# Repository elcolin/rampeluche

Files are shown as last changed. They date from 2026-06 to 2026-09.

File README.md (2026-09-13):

# Rampeluche

This project aims to create a two wheel bot capable of SLAM and autonomous navigation.

## Current development

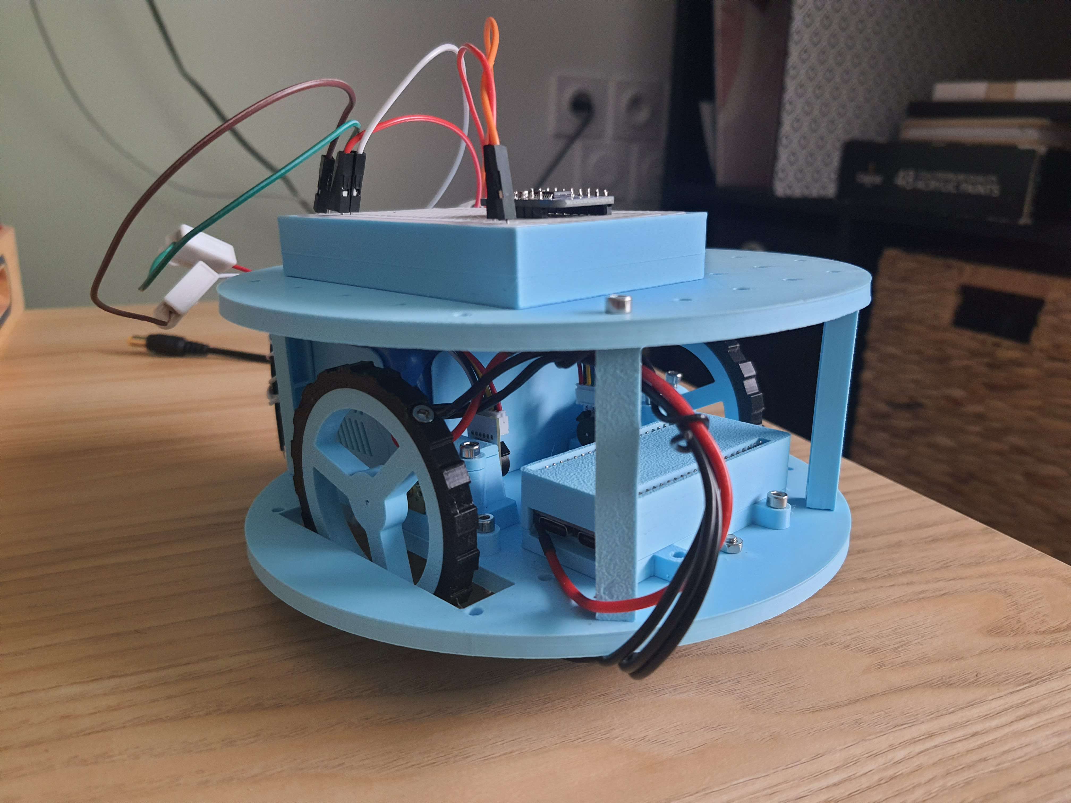
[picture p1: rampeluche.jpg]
Rampeluche


- Keyboard teleoperation (w/a/s/d) over Wi-Fi (SoftAP + raw TCP), with a
  motor safety cutoff if the client disconnects
- Differential drive control through the H-bridge motor driver
- Lidar wired up and its Express Scan frames decoded (checksum-verified,
  angle/distance interpolated), not yet used for obstacle avoidance or SLAM
- Unit tests (Unity, `pio test -e native`) covering the keyboard control
  logic, the Wi-Fi teleop session logic (key decoding, safety timeout),
  RPLidar request-packet encoding, and RPLidar decoding logic

See [rampeluche-esp32/README.md](rampeluche-esp32/README.md) for details.

Issues :  
    - Reduce torque on stall for wheel -> digs into the plastic

## Datasheets

### Motor

Micro motors in the wheels.  
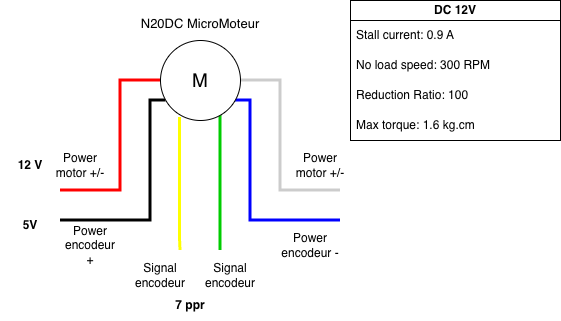
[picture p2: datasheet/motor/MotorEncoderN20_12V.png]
Motor Wheel
    

### Microcontroller

- S3 ESP-32-S3-DevKitC-1 WROOM-1-N16R8
    [Datasheet](datasheet/esp-dev-kits-en-master-esp32s3.pdf)

### Buck convertissor

- VERTER 5V USB Buck-Boost - 500mA from 3V-5V / 1000ma from 5V-12V
    [Datasheet](datasheet/VERTER-5V-USB-Buck-Boost.pdf)

### Motor Driver

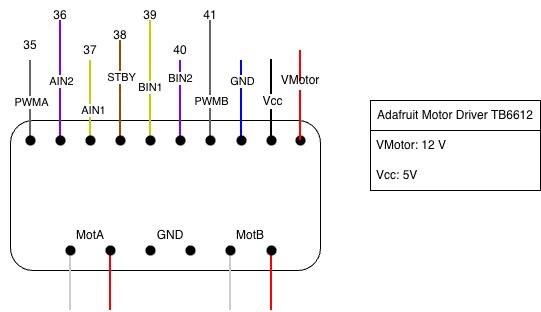
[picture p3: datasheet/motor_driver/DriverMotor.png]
Motor Driver Pinout


- Adafruit TB6612 1.2A DC/Stepper Motor Driver Breakout Board
    [Datasheet](datasheet/motor_driver/adafruit-tb6612-h-bridge-dc-stepper-motor-driver-breakout.pdf)
- TB6612 Chip
    [Datasheet](datasheet/motor_driver/TB6612FNG_datasheet_en_20121101.pdf)

### IMU

- Adafruit LSM9DS1 Accelerometer + Gyro + Magnetometer 9-DOF Breakout
    [Datasheet](datasheet/adafruit-lsm9ds1-accelerometer-plus-gyro-plus-magnetometer-9-dof-breakout.pdf)

### Lidar

- SLAMTEC rplidar A2M8
    [Datasheet](datasheet/LD208_SLAMTEC_rplidar_datasheet_A2M8_v2.6_en.pdf)

## CAD

3d files can be found in the cad file : Lots of models are ORP plateform based.
    [Parts](https://openroboticplatform.com/user:ColorGama)

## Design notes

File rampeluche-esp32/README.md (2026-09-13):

# Rampeluche ESP32

Firmware embarqué du robot Rampeluche : un ESP32-S3 pilote deux moteurs DC
(traction différentielle) et un LIDAR RPLidar, et se laisse téléopérer au
clavier via Wi-Fi (SoftAP + socket TCP brut).

Voir le [README du projet global](../README.md) pour le contexte matériel
(châssis, moteurs, datasheets).

## Vue d'ensemble

```
tools/keyboard_client.py          (PC, Wi-Fi)
        | touche w/a/s/d, toutes les 150 ms, via TCP:1234
        v
   ESP32 SoftAP "ESP32_Control"
        |
   src/main.cpp  (boucle principale)
        |-- lit un octet sur le socket client -> WifiTeleopServer::onKeyReceived()
        |     `-- delegue a KeyboardControl::decodeKey() -> DriveCommand (gauche/droite)
        |-- pas d'octet dispo -> WifiTeleopServer::checkTimeout() (delegue a keyTimedOut())
        |-- applyDriveCommand()/applyMotorCommand() -> DriverMotor -> Motor -> pins PWM/IN1/IN2
        |
        `-- LidCtl.poll(onLidarPoints) -> Serial2 -> RplidarDecoder::StreamDecoder -> Serial (debug)
```

Le robot n'exécute aucune logique de navigation autonome à ce stade : c'est
une téléopération manuelle. Le LIDAR est câblé et initialisé, ses trames sont
décodées par `lib/RplidarDecoder`, mais uniquement pour être affichées sur le
port série (pas encore exploitées pour éviter les obstacles ou faire du
SLAM).

## Structure du code

```
include/            Headers partagés (déclarations de classes, pins)
  pins.hpp            Table de correspondance broches ESP32 <-> matériel
  DriverMotor.h       Regroupe les 2 moteurs (gauche/droite)
  Motor.hpp           Pilotage d'un moteur DC via pont en H
  LidarController.hpp Pilotage du RPLidar sur Serial2 (setup, scan express,
                       poll()) ; delegue l'encodage des requetes a
                       lib/RplidarProtocol et le decodage des trames a
                       lib/RplidarDecoder

src/                 Implémentation, dépend d'Arduino.h / matériel réel
  main.cpp            setup()/loop() : Wi-Fi, serveur TCP (lecture bas niveau du
                       socket uniquement), boucle de pilotage, poll() du LIDAR
                       (LidarController -> RplidarDecoder)
  DriverMotor.cpp
  Motor.cpp
  LidarController.cpp

lib/KeyboardControl/  Logique pure de décision "touche -> commande moteur"
  KeyboardControl.hpp   Types (MotorAction, MotorCommand, DriveCommand),
                         constantes de vitesse/timeout, decodeKey(), keyTimedOut()
  KeyboardControl.cpp   Implémentation, aucune dépendance Arduino/matériel

lib/WifiTeleopServer/ Logique pure de session téléop (au-dessus de KeyboardControl)
  WifiTeleopServer.hpp  Classe WifiTeleopServer : onKeyReceived() (touche -> DriveCommand,
                         reset du timeout), checkTimeout() (latch du stop de sécurité)
  WifiTeleopServer.cpp  Implémentation, aucune dépendance Arduino/matériel

lib/RplidarDecoder/   Logique pure de décodage des paquets "Express Scan"
                      du RPLIDAR A2M8 (synchro, checksum, interpolation
                      angle/distance, resynchronisation sur un flux d'octets)
  RplidarDecoder.hpp    Types (ScanPoint), fonctions de décodage d'un paquet
                        (decodeCapsulePair()...), StreamDecoder (etat +
                        buffering incrementaux, callback de points)
  RplidarDecoder.cpp    Implémentation, aucune dépendance Arduino/matériel

lib/RplidarProtocol/  Logique pure d'encodage des paquets de requête envoyés
                      au RPLIDAR (en-tête, commande, payload, checksum XOR)
  RplidarProtocol.hpp   buildRequestPacket(), requestPacketSize()
  RplidarProtocol.cpp   Implémentation, aucune dépendance Arduino/matériel

test/test_keyboard_control/
  test_main.cpp        Tests unitaires (Unity) de decodeKey()/keyTimedOut(),
                        exécutés hors cible (pas besoin d'ESP32)

test/test_wifi_teleop_server/
  test_main.cpp        Tests unitaires (Unity) de WifiTeleopServer (décodage touche,
                        déclenchement/latch du timeout), exécutés hors cible

test/test_rplidar_decoder/
  test_main.cpp        Tests unitaires (Unity) de lib/RplidarDecoder sur des
                        paquets synthétiques (synchro, checksum, interpolation,
                        resynchronisation), hors cible

test/test_rplidar_protocol/
  test_main.cpp        Tests unitaires (Unity) de lib/RplidarProtocol :
                        encodage de requête (avec/sans payload), checksum,
                        dimensionnement de buffer via requestPacketSize()

test/test_rplidar_decoder_capture/
  test_main.cpp        Test complémentaire optionnel : rejoue une capture
                        réelle du flux lidar (test/fixtures/*.bin, non
                        versionnée) ; s'auto-ignore si le fichier est absent

tools/
  keyboard_client.py    Client Python (PC) : capte w/a/s/d au clavier et les
                         envoie en boucle au robot par TCP
  capture_rplidar_serial.py  Enregistre un flux série (relais Serial2 du
                         lidar) dans un fichier binaire, pour test/fixtures/
                         (voir test/fixtures/README.md)
  requirements.txt

platformio.ini        2 environnements : esp32-s3-devkitc-1 (firmware réel)
                       et native (tests unitaires sur machine de dev)
```

## Choix d'architecture

### Séparer la logique pure du code matériel

`lib/KeyboardControl` ne dépend que de `<cstdint>`, pas d'`Arduino.h`. La
fonction `decodeKey()` (touche -> commandes moteur gauche/droite) et
`keyTimedOut()` (calcul du délai de sécurité) sont des fonctions pures,
sans effet de bord matériel. Ça permet de les tester unitairement sur la
machine de dev, sans flasher un ESP32 à chaque changement, via
l'environnement `native` de PlatformIO :

```sh
pio test -e native
```

`lib/WifiTeleopServer` regroupe la logique d'une session téléop au-dessus de
`KeyboardControl` : la classe `WifiTeleopServer` ne dépend elle non plus que
de `KeyboardControl.hpp`, pas d'`Arduino.h`/`WiFiClient`. `onKeyReceived()`
délègue le décodage à `decodeKey()` et réarme le timeout ; `checkTimeout()`
délègue à `keyTimedOut()` et ne remonte l'ordre de stop qu'une seule fois par
période de silence (`TimeoutResult::triggered`). Testable elle aussi sous
`pio test -e native` (voir `test/test_wifi_teleop_server`).

`src/main.cpp` reste le seul endroit qui connecte cette logique au matériel
réel : la boucle `while (client.connected())` lit les octets bruts du socket
TCP et les pousse à `WifiTeleopServer::onKeyReceived()` (ou appelle
`checkTimeout()` quand rien n'est disponible), puis `applyDriveCommand()`/
`applyMotorCommand()` traduisent le `DriveCommand`/`MotorCommand` obtenu en
appels `Motor::setMotorForward/Backward/stopMotor`. `lib/RplidarDecoder` et
`lib/RplidarProtocol` (voir plus bas) suivent le même principe pour le
protocole LIDAR (décodage des trames reçues / encodage des requêtes
envoyées), via `LidarController::poll()`/`startExpressScan()`. Ce sont les
quatre modules du firmware couverts par des tests aujourd'hui
(`KeyboardControl`, `WifiTeleopServer`, `RplidarDecoder`, `RplidarProtocol`) ;
le reste (moteurs, pilotage LIDAR bas niveau, Wi-Fi bas niveau) n'est
vérifiable qu'en conditions réelles, faute d'abstraction matérielle
testable.

### Coupure de sécurité si le client décroche

`WifiTeleopServer` mémorise l'horodatage de la dernière touche reçue. Si
aucune touche n'arrive pendant `KEY_TIMEOUT_MS` (500 ms, défini dans
`KeyboardControl.hpp`), `checkTimeout()` retourne une commande d'arrêt pour
les deux moteurs, que `main.cpp` applique via `applyDriveCommand()`. Ça
protège contre une perte de connexion Wi-Fi ou un client qui plante avec le
robot lancé. Côté client Python, l'envoi est cadencé à 150 ms
(`SEND_INTERVAL`), volontairement bien en dessous du timeout firmware, pour
qu'un simple relâchement de touche coupe les moteurs de façon réactive sans
attendre le timeout de sécurité.

### Wi-Fi SoftAP + TCP brut, pas de protocole applicatif

L'ESP32 monte son propre point d'accès (`ESP32_Control`) et un
`WiFiServer` TCP sur le port 1234. Le protocole est volontairement minimal :
un caractère par commande (`w`/`a`/`s`/`d`, tout le reste = arrêt), pas de
framing ni de librairie réseau tierce. Suffisant pour une téléopération
directe ; pas conçu pour survivre à plusieurs clients simultanés ou à des
pertes de paquets (TCP masque une partie du problème, mais rien ne gère une
reconnexion propre du serveur après déconnexion du client).

### Contrôle moteur : pont en H, vitesse en pourcentage

`Motor` pilote un pont en H classique (2 entrées logiques IN1/IN2 + 1 PWM,
table de vérité documentée en commentaire dans `DriverMotor.h`). L'API
publique (`setMotorForward/Backward(uint8_t per_speed)`) prend un
pourcentage 0-100 plutôt qu'une valeur PWM brute, pour découpler l'appelant
(`KeyboardControl`, qui définit `FORWARD_SPEED`/`BACKWARD_SPEED`/
`TURN_SPEED` en pourcentage) de la résolution PWM réelle du driver.
`DriverMotor` regroupe les deux `Motor` (gauche/droite) et gère la broche
`STBY` commune aux deux ponts.

### LIDAR : protocole RPLidar "express scan"

`LidarController` orchestre le pilotage du RPLidar sur `Serial2` (`setup()`,
`startExpressScan()`, `poll()`), mais délègue le protocole série à deux libs
pures (`<cstdint>` seul, pas d'`Arduino.h`), testables hors cible via
`pio test -e native`, sur le même principe que `lib/KeyboardControl` :

- `lib/RplidarProtocol` construit les paquets de requête envoyés au lidar
  (`buildRequestPacket()` : en-tête `0xA5` + commande + taille payload +
  payload + checksum XOR). `requestPacketSize(payloadLen)` calcule la taille
  exacte de buffer requise (overhead 4 octets + payload) ; `startExpressScan()`
  dimensionne son buffer avec ce helper plutôt qu'un magic number, pour
  éviter un débordement si la taille du payload change.
- `lib/RplidarDecoder` décode les paquets renvoyés par le lidar (voir
  ci-dessous).

Chaque paquet "capsule" (84 octets) porte un angle de départ en virgule fixe
Q6 (degrés x64) et 16 "cabines" de 2 points chacune (distance en Q2, mm x4,
+ offset d'angle en Q3, 1/8 de degré), format propriétaire Slamtec. L'angle
de chaque point n'étant fiable qu'au début du paquet, `decodeCapsulePair()`
interpole linéairement entre les angles de départ de deux paquets
consécutifs avant d'appliquer l'offset Q3 de la cabine. `StreamDecoder`
consomme le flux d'octets brut de l'UART : il se resynchronise seul sur les
demi-octets de synchro (`0xA`/`0x5`) si l'alignement est perdu (bruit, octet
manqué, redémarrage), vérifie le checksum XOR de chaque paquet, et restitue
les points valides via un callback (`ScanPoint{angle_deg, distance_mm}`).

`LidarController::poll(callback)` lit les octets disponibles sur `Serial2`
(non bloquant) et les transmet au `StreamDecoder`. `main.cpp` l'appelle à
chaque tour de `loop()`, y compris en continu pendant qu'un client de
téléop est connecté (`onLidarPoints` fait un simple `Serial.print` de debug)
— sinon le petit buffer RX matériel de l'UART déborde et le décodage
dégénère en resynchronisations/erreurs de checksum. Aucune structure de
données exploitable par le reste du firmware n'est produite pour l'instant
(pas encore de nuage de points en mémoire, pas de consommateur).

Le décodeur est testé sur des paquets synthétiques
(`test/test_rplidar_decoder`) et, en complément optionnel, sur une capture
réelle du flux série (`test/test_rplidar_decoder_capture`,
`tools/capture_rplidar_serial.py`, voir `test/fixtures/README.md`).
L'encodage des requêtes (`lib/RplidarProtocol`) est testé séparément
(`test/test_rplidar_protocol`) sur des vecteurs de référence issus de la
doc protocole RPLIDAR.

## Table des broches (`include/pins.hpp`)

| Broche ESP32 | Fonction |
|---|---|
| 11 | LIDAR : contrôle moteur (PWM) |
| 12 | LIDAR : RX (UART Serial2) |
| 13 | LIDAR : TX (UART Serial2) |
| 39 / 40 / 41 | Moteur droit : IN1 / IN2 / PWM |
| 37 / 36 / 35 | Moteur gauche : IN1 / IN2 / PWM |
| 38 | STBY commun aux deux ponts en H |

## Compiler, flasher, tester

```sh
# Firmware réel (ESP32-S3), depuis rampeluche-esp32/
pio run -e esp32-s3-devkitc-1
pio run -e esp32-s3-devkitc-1 -t upload
pio device monitor -b 115200

# Tests unitaires (lib/KeyboardControl, lib/WifiTeleopServer,
# lib/RplidarDecoder, lib/RplidarProtocol), sur la machine de dev (pas d'ESP32 requis)
pio test -e native
```

Sur macOS, si `pio test -e native` échoue au link avec une erreur du type
`archive member '/' not a mach-o file`, c'est qu'un `ar` GNU (ex: via
Homebrew binutils) passe avant celui d'Apple dans le `PATH`. Contournement :

```sh
PATH="/usr/bin:$PATH" pio test -e native
```

### Piloter le robot

```sh
cd tools
pip install -r requirements.txt
python3 keyboard_client.py            # se connecte à 192.168.4.1:1234 par défaut
```

Touches : `w` avancer, `s` reculer, `a`/`d` pivoter sur place, relâcher
= arrêt, `q`/Échap pour quitter.

## Dette technique connue

- Le décodage LIDAR (`LidarController::poll()` + `lib/RplidarDecoder`) ne
  fait encore que logger les points sur `Serial` (`onLidarPoints` dans
  `main.cpp`) ; il n'y a pas encore de consommateur de ces données (pas
  d'évitement d'obstacle, pas de SLAM).
- Du code d'encodeur odométrique (interruption `encoderISR`, comptage de
  ticks) est présent dans `main.cpp` mais commenté / non branché.
- `LidarController::startExpressScan()` bloque ~500 ms (`delay()`) le temps
  que le moteur du lidar atteigne sa vitesse nominale. Appelé une seule fois
  au démarrage (premier tour de `loop()`), donc sans impact récurrent
  aujourd'hui, mais à traiter avant toute boucle temps réel plus stricte.
- La boucle `while (client.connected())` de `main.cpp` reste bloquante (elle
  ne rend la main qu'à la déconnexion du client) ; l'extraction de
  `WifiTeleopServer` n'a pas touché à ce point.
- `DriverMotor.h` utilise l'extension `.h` alors que le reste des headers
  du projet utilise `.hpp` — incohérence mineure de nommage.

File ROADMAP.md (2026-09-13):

# Roadmap Rampeluche

Document de suivi technique — état vérifié dans le code/git au 2026-09-13
(mis à jour le même jour : conflit PR #3, nettoyage `WifiHandler.hpp`
constaté fait, extraction `WifiTeleopServer`/`Motor` ajoutée aux actions).
Ne remplace pas README.md / CLAUDE.md (Stack et Architecture y restent la
source de vérité) ; ce fichier trace uniquement les jalons et leurs
dépendances.

## État réel vérifié

- `main` est à jour avec `origin/main` (dernier merge : PR #17, `/feature`
  slash command — tooling agents, hors périmètre firmware de ce document).
  Deux branches restent non mergées :
  - `feat/quadrature-encoders` : ajoute `lib/QuadratureDecoder/` + tests
    Unity (TDD respecté), `Encoder`/`EncoderController`. Pas de PR ouverte,
    juste une branche locale/remote. Ne dépend de rien d'autre, aucun
    conflit connu avec `main`.
  - PR #3 `worktree-rplidar-decoder` (**DRAFT**) : ajoute `lib/RplidarDecoder/`
    (décodeur Express Scan pur, sans `Arduino.h`, fidèle au SDK SLAMTEC),
    12 tests Unity, validation sync/checksum, `LidarController::poll()`,
    outil de capture `tools/capture_rplidar_serial.py`. **Mise à jour :**
    `gh pr view 3` renvoie désormais `mergeable: CONFLICTING` avec `main`
    — un rebase est nécessaire avant de sortir du DRAFT, en plus du
    rebranchement dans `src/main.cpp`.
- `src/main.cpp` (sur `main`) contient encore le prototype `parseExpressPacket()`
  ad-hoc (décodage non testé, pas de checksum ni resynchronisation) et une
  boucle téléop bloquante `while (client.connected())`. Le WiFi/TCP
  (`WiFiServer`, `WiFiClient`, parsing des touches) reste géré inline dans
  ce fichier, sans module dédié.
- `include/WifiHandler.hpp` (coquille vide) a été **supprimé** (PR #19,
  mergée) : la dette "header qui ne fait rien" a disparu, mais le problème
  de fond (Wi-Fi/TCP non extrait en module testable) reste entier — voir
  action court terme "extraire `WifiTeleopServer`" ci-dessous.
- `include/Motor.hpp`/`src/Motor.cpp` et `include/DriverMotor.h`/
  `src/DriverMotor.cpp` : logique PWM/direction correcte (table de vérité
  H-bridge documentée en commentaire) mais couplée à `Arduino.h` dès la
  déclaration — aucune logique pure extraite, donc aucun test Unity
  possible sur ce périmètre aujourd'hui.
- Torque moteur (issue #1, "Configure esp32 signal for torque reduction") :
  **fermée**. `Motor::stopMotor()` met `IN1=LOW, IN2=LOW` ce qui correspond
  bien au mode "Stop" (roue libre) du driver, pas au mode "Short brake" — le
  fix attendu a bien été implémenté. Aucune incohérence de code résiduelle
  détectée sur ce point ; à re-vérifier physiquement si le symptôme
  (moteur qui creuse le plastique) réapparaît.
- IMU LSM9DS1 : aucune trace dans `lib/`, `src/`, `include/` — pas encore
  câblée ni codée. La fusion capteurs (Lidar + IMU) ne peut pas démarrer
  avant son intégration.
- Migration RTOS : le core Arduino-ESP32 embarque déjà FreeRTOS (`loop()`
  tourne dans une tâche FreeRTOS), mais le firmware ne l'utilise pas
  explicitement (une seule boucle séquentielle) — voir issue #13 ci-dessous
  pour la conséquence concrète de ce choix.

### Dette identifiée par le `code-reviewer` (déjà en issues GitHub)

- **Issue #13** — `main.cpp` : la boucle `while (client.connected())`
  bloque tout le reste de `loop()` (dont la lecture `Serial2` du Lidar) tant
  qu'un client téléop reste connecté ; un `delay(500)` supplémentaire
  retarde encore la reprise après déconnexion. Concrètement : dès qu'on
  pilote le robot, le flux Lidar est perdu/désynchronisé. C'est la preuve
  par le code que le découplage FreeRTOS (jalon **M2**) n'est pas un
  exercice théorique mais un prérequis pour que téléop et lecture Lidar
  coexistent.
- **Issue #14** — Logique de protocole RPLidar (`parseExpressPacket`,
  `compute_checksum`, `build_request` dans `main.cpp`/`LidarController.cpp`)
  non extraite dans une lib testable, sans tests Unity, sans validation de
  checksum/sync (désync silencieuse possible). **La PR #3 traite déjà ce
  point** (extraction + 12 tests + validation checksum/sync) ; le travail
  restant est de sortir la PR du mode DRAFT, la rebrancher dans `main.cpp`
  et fermer l'issue #14 à la fusion — pas de le refaire dans un jalon
  ultérieur.

## Prochaines étapes court terme

1. **Merger `feat/quadrature-encoders` (ouvrir une PR).** Indépendant du
   reste, déjà TDD-compliant, aucun conflit connu — à sortir en premier,
   avant la PR #3, pour limiter le risque de conflits supplémentaires sur
   `main.cpp`.
2. **Rebaser la PR #3 sur `main` puis la sortir du DRAFT.** `gh pr view 3`
   montre `mergeable: CONFLICTING` — le rebase est un préalable, distinct
   du rebranchement applicatif. Une fois rebasée : remplacer le bloc
   `Serial2.available() >= 84` / `parseExpressPacket()` de `main.cpp` par
   `LidCtl.poll(onLidarPoints)` (patch documenté dans la description de la
   PR). Ferme l'issue #14.
3. **Extraire un module `lib/WifiTeleopServer/`** pour la logique
   actuellement inline dans `main.cpp` (parsing du flux TCP, gestion du
   timeout clavier) — remplace l'ancienne action "nettoyer
   `WifiHandler.hpp`" (déjà faite via PR #19, mais qui n'a fait que
   supprimer la coquille vide sans combler le vide fonctionnel). Prérequis
   structurel avant de pouvoir écrire l'action 4 sans tout mélanger dans
   `main.cpp`.
4. **Corriger la boucle téléop bloquante (issue #13).** Une fois 1-3
   mergés, remplacer `while (client.connected())` par un poll non bloquant
   dans `loop()` (solution minimale, sans RTOS) OU basculer directement sur
   deux tâches FreeRTOS (téléop / capteurs) si le jalon **M2** est engagé en
   parallèle. Nécessaire avant tout travail de fusion Lidar+IMU puisque le
   Lidar est aujourd'hui silencieusement coupé pendant la conduite.
5. **Extraire la logique PWM/direction pure de `Motor`** dans une fonction
   testable (ex. "quel `IN1`/`IN2`/duty cycle pour telle vitesse/direction
   demandée", sur le modèle de `KeyboardControl`) — aujourd'hui ce calcul
   est correct mais entièrement non testé faute d'extraction hors
   `Arduino.h`.
6. **Intégrer l'IMU LSM9DS1** (lecture brute + tests Unity sur le décodage
   des registres, sur le modèle de `lib/RplidarDecoder`). Aucun travail de
   fusion capteurs n'est possible avant cette étape : c'est un prérequis
   dur pour le jalon **M3**.

## Méthodes/approches possibles

### Structure du code (`lib/<Module>` vs découplage message-passing anticipé)

- **Option A — Un `lib/<Module>` par capteur/actionneur, `main.cpp` réduit
  à un orchestrateur mince (recommandé, prolonge le pattern déjà utilisé
  par `KeyboardControl`, `RplidarDecoder`, `QuadratureDecoder`).**
  Avantages : cohérent avec ce qui passe déjà en TDD ; chaque module reste
  testable isolément (`pio test -e native`) ; chaque module devient une
  unité naturellement encapsulable dans une tâche FreeRTOS pour M2.
  Inconvénients : demande de la discipline pour ne pas laisser la logique
  métier refuir dans `main.cpp` (dérive déjà observée avec
  `parseExpressPacket`).
- **Option B — Introduire dès maintenant des files/queues de
  message-passing entre modules, avant même M2.** Avantages : prépare le
  découplage FreeRTOS en une seule fois. Inconvénients : sur-ingénierie
  tant qu'il n'y a qu'une seule tâche (`loop()`) — complexité ajoutée sans
  bénéfice avant qu'il y ait une vraie concurrence à gérer.
- **Recommandation :** Option A maintenant (actions court terme 1-6
  ci-dessus) ; introduire les files/queues (Option B) seulement au moment
  de M2, quand plusieurs tâches FreeRTOS existeront réellement.

### RTOS : FreeRTOS (déjà présent via Arduino-ESP32) vs bare-metal

- **Option A — Tâches FreeRTOS explicites (recommandé).** Le core
  Arduino-ESP32 tourne déjà sur FreeRTOS ; il suffit de créer des tâches
  dédiées (`xTaskCreatePinnedToCore`) pour téléop, lecture Lidar,
  lecture IMU, contrôle moteur, avec des files (`xQueueSend`/`Receive`)
  pour le découplage. Avantages : résout directement l'issue #13 sans
  réécriture du framework, exploite les deux cœurs du S3, API bien
  documentée. Inconvénients : discipline requise sur les priorités/tailles
  de pile, risque de race conditions sur les ressources partagées
  (`Serial2`, moteurs) si mal cloisonné.
- **Option B — Bare-metal / boucle unique optimisée.** Réécrire `loop()`
  en state machine non bloquante (polling avec timeouts courts partout).
  Avantages : pas de nouvelle dépendance, contrôle total du timing.
  Inconvénients : ne s'attaque pas au fond du problème (un seul thread
  d'exécution) — dès qu'on ajoute IMU + SLAM + téléop + moteurs, la
  complexité de la state machine explose et redevient fragile, ce qui va
  à l'encontre de l'objectif explicite de migration RTOS du CLAUDE.md.
- **Recommandation :** Option A. Le coût de migration est faible (le
  runtime est déjà là), elle répond concrètement à l'issue #13, et elle
  seule tient dans la durée face à l'ajout de l'IMU + SLAM.

### Fusion Lidar + IMU

- **Option A — Complementary/Madgwick filter (orientation IMU) +
  recalage Lidar en aval (scan matching léger, type ICP 2D simplifié).**
  Avantages : coût CPU compatible ESP32-S3 (pas de FPU dédiée mais
  cœurs à 240 MHz suffisants pour un filtre léger), latence prévisible,
  bibliothèques existantes (ex. adaptations de Madgwick/Mahony en C).
  Inconvénients : dérive à long terme si pas de correction extérieure,
  scan matching simplifié moins robuste qu'un SLAM complet en environnement
  dynamique.
- **Option B — EKF (Extended Kalman Filter) fusionnant IMU + odométrie
  encodeurs + recalage Lidar, façon robot_localization/ROS mais réimplémenté
  en C léger.** Avantages : fusion statistiquement correcte, exploite les
  encodeurs déjà présents (`feat/quadrature-encoders`), extensible vers du
  SLAM (ex. gmapping-like) plus tard. Inconvénients : plus complexe à
  implémenter/tester en TDD pur C++ embarqué, coût CPU/mémoire plus élevé
  (matrices, inversions), à valider par profiling sur cible avant de
  s'engager.
- **Recommandation :** commencer par l'Option A (complementary filter +
  odométrie encodeurs) comme brique M3, car les encodeurs et le décodeur
  Lidar existent déjà quasiment testés — livrable rapide et vérifiable en
  Unity. Migrer vers l'EKF (Option B) seulement quand un besoin concret de
  précision de localisation apparaît (jalon SLAM, M5+), pas avant.

## Roadmap par jalons

- **M0 — Consolidation de l'existant (prérequis à tout le reste)**
  - Merge `feat/quadrature-encoders`, rebase + sortie de DRAFT + merge PR #3
    (branchement `LidCtl.poll()` dans `main.cpp`, ferme #14).
  - Extraction `lib/WifiTeleopServer/` (remplace l'ancienne action
    "nettoyer `WifiHandler.hpp`", déjà faite via PR #19).
  - Fix issue #13 (poll non bloquant ou premier découplage FreeRTOS minimal).
  - Extraction de la logique PWM/direction pure de `Motor` (testable Unity).
  - Dépendances : aucune — c'est le socle de tout ce qui suit.

- **M1 — Lidar exploité en continu**
  - Consommer réellement les `ScanPoint` produits par `LidCtl.poll()`
    (aujourd'hui juste affichés en `Serial.print` dans l'exemple de la
    PR #3) : structure de données d'un scan complet, exposition vers le
    reste du firmware.
  - Dépend de M0 (décodeur branché + boucle non bloquante, sinon le flux
    reste coupé pendant la téléop).

- **M2 — Découplage FreeRTOS (tâches téléop / Lidar / moteurs)**
  - Implémenter l'option A ci-dessus (tâches + files) si le fix minimal de
    M0 pour #13 n'est qu'un pansement (poll) plutôt qu'une vraie séparation.
  - Dépend de M0 ; conditionne la suite car IMU + fusion + SLAM ajoutent
    des flux concurrents supplémentaires qu'une boucle unique ne pourra
    plus absorber.

- **M3 — Intégration IMU LSM9DS1 + odométrie**
  - Driver I2C/SPI + décodage registres testé en Unity (sur le modèle
    `lib/RplidarDecoder`), fusion basique avec les encodeurs
    (`feat/quadrature-encoders`) pour une estimation de pose odométrique.
  - Dépend de M2 (une tâche IMU dédiée a besoin du découplage RTOS pour ne
    pas être bloquée par la téléop, même problème que le Lidar aujourd'hui).

- **M4 — Fusion Lidar + IMU (complementary filter, Option A)**
  - Recalage des scans Lidar avec l'orientation/déplacement estimés par
    IMU+encodeurs (M3).
  - Dépend de M1 (scans exploitables) et M3 (odométrie disponible).

- **M5 — Cartographie / SLAM léger**
  - Occupancy grid ou scan-matching incrémental, adapté aux ressources
    ESP32-S3 (pas de SLAM complet type Cartographer sur ce MCU — à évaluer :
    exécution locale minimale vs déport du calcul lourd sur un hôte via
    WiFi, à trancher une fois M4 mesuré en pratique).
  - Dépend de M4.

- **M6 — Navigation autonome de base (évitement d'obstacles)**
  - Boucle de contrôle réactive sur la carte/scan fusionné, sans ML.
  - Dépend de M5 (ou au minimum de M4 si une navigation réactive pure
    Lidar+IMU suffit avant d'avoir une carte).

- **M7 — Machine learning**
  - Une fois qu'un pipeline de perception fiable et testé existe
    (M4-M6), envisager un modèle embarqué (classification d'obstacles,
    apprentissage de trajectoire) — prématuré tant que la donnée capteur
    fusionnée n'est pas stable et vérifiée par tests.
  - Dépend de M4 au minimum (données de fusion propres), idéalement M5/M6.

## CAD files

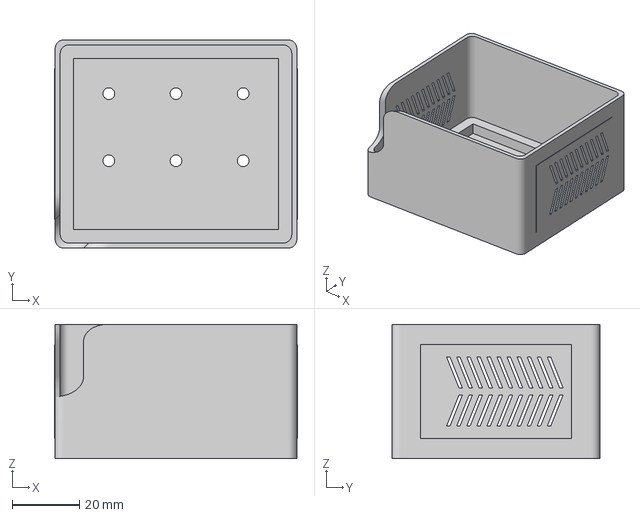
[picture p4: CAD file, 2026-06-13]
cad/battery holder.3mf
72.4 x 62.0 x 40.0 mm

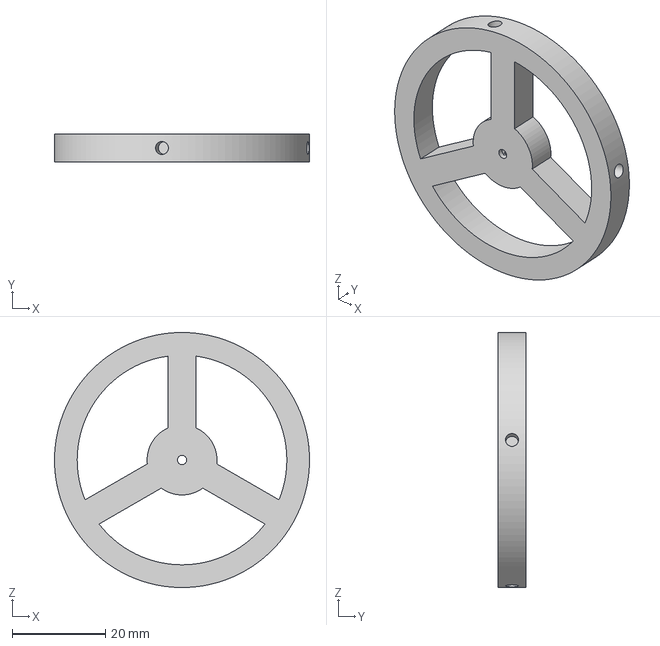
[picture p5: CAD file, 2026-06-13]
cad/roue_n20.3mf
54.7 x 6.00 x 54.7 mm

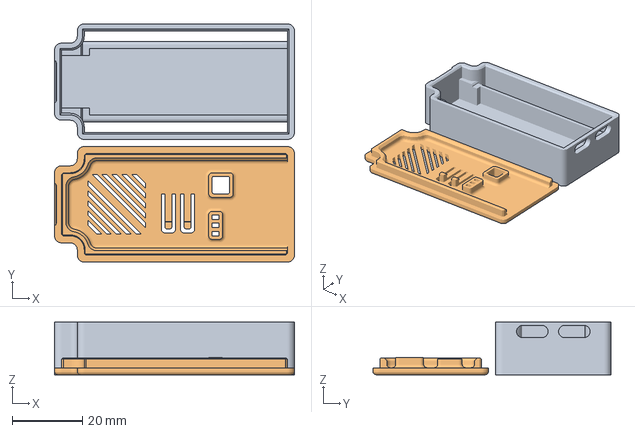
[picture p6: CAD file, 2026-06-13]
cad/ESP32_S3_WROOM_Case.3mf
68.5 x 68.0 x 15.0 mm
ESP32_S3_WROOM_Case.stl_1
ESP32_S3_WROOM_Case.stl_2

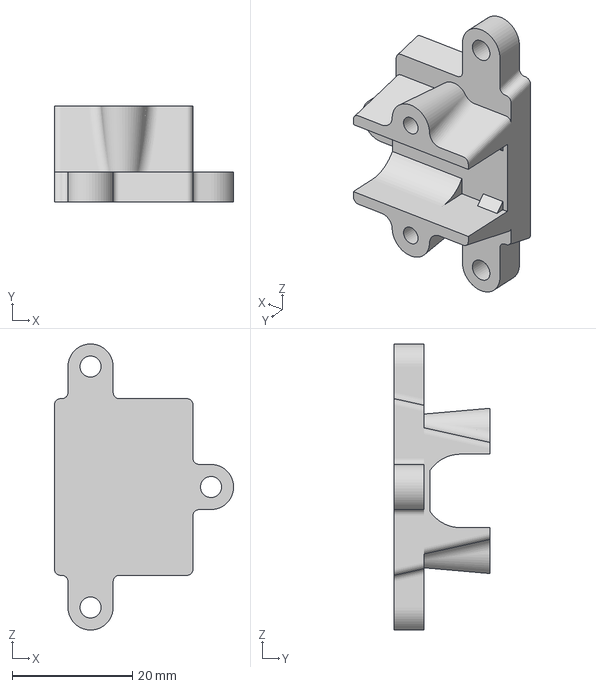
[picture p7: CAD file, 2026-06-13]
cad/motormount.3mf
29.7 x 16.0 x 47.5 mm

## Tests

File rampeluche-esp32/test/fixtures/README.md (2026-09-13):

# Fixtures de test (captures reelles du RPLIDAR A2M8)

`test_rplidar_decoder_capture` verifie le decodeur sur un enregistrement reel
du flux serie du lidar, en complement des paquets synthetiques de
`test_rplidar_decoder`. Ce fichier binaire n'est pas versionne (specifique a
un capteur/une session de capture) : chacun genere le sien localement.

## 1. Generer la capture

### Via l'ESP32 (cablage actuel : lidar relie uniquement a Serial2)

Remplacer temporairement le contenu de `loop()` dans `src/main.cpp` par un
simple relais brut Serial2 -> Serial :

```cpp
void loop() {
    static bool started = false;
    if (!started) {
        delay(500);
        LidCtl.startExpressScan();
        started = true;
    }
    while (Serial2.available()) {
        Serial.write(Serial2.read());
    }
}
```

Flasher (`pio run -t upload`), puis sur la machine de dev (`pip install
pyserial` si besoin) :

```
python3 tools/capture_rplidar_serial.py <port_serie_esp32> 5 test/fixtures/rplidar_a2m8_express_scan.bin
```

`<port_serie_esp32>` : le port USB de l'ESP32 (visible dans
`pio device monitor` ou le moniteur serie, ex. `/dev/tty.usbmodem14201` sur
macOS, `COM5` sur Windows). 5 secondes suffisent largement a couvrir
plusieurs tours, meme a vitesse de rotation reduite.

Remettre ensuite `loop()` dans son etat normal une fois la capture faite :
ce bloc n'est qu'un outil de capture, pas du code a garder en place.

### Via un adaptateur USB-TTL branche directement sur le lidar

Si le RPLIDAR est cable sur un adaptateur USB-TTL independant de l'ESP32, le
meme script peut lire directement le port serie du lidar. Il faut alors,
avant de lancer la capture : alimenter/piloter le moteur (ce projet utilise
une broche PWM dediee, pas de DTR automatique comme sur l'adaptateur
officiel Slamtec) et envoyer la commande Express Scan
(`0xA5 0x82 0x05 0x00 0x00 0x00 0x00 0x00 0x22`) sur ce port.

## 2. Emplacement attendu

```
test/fixtures/rplidar_a2m8_express_scan.bin
```

`test_rplidar_decoder_capture` l'ignore proprement (`IGNORE`, pas `FAIL`)
si le fichier est absent : `pio test -e native` passe sans lui, c'est un
test complementaire pour qui a le materiel sous la main.

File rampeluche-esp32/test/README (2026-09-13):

This directory is intended for PlatformIO Test Runner and project tests.

Unit Testing is a software testing method by which individual units of
source code, sets of one or more MCU program modules together with associated
control data, usage procedures, and operating procedures, are tested to
determine whether they are fit for use. Unit testing finds problems early
in the development cycle.

More information about PlatformIO Unit Testing:
- https://docs.platformio.org/en/latest/advanced/unit-testing/index.html

## test_keyboard_control

Tests unitaires (Unity) de la logique pure de `lib/KeyboardControl`
(decodage touche -> commande moteur, timeout de securite). Ils tournent
hors cible, sans ESP32 ni Arduino.h :

    pio test -e native

Sur macOS, si le linker echoue avec une erreur du type
`archive member '/' not a mach-o file`, c'est qu'un `ar` GNU (ex: via
Homebrew binutils) passe avant celui d'Apple dans le PATH et produit des
archives dans le mauvais format. Contournement :

    PATH="/usr/bin:$PATH" pio test -e native

## test_rplidar_decoder

Tests unitaires (Unity) de la logique pure de `lib/RplidarDecoder`
(decodage des paquets Express Scan du RPLIDAR A2M8 : synchro, checksum,
interpolation angle/distance, resynchronisation sur un flux d'octets). Meme
commande que ci-dessus (`pio test -e native`), meme contournement macOS si
necessaire.

## test_rplidar_decoder_capture

Test complementaire au precedent : rejoue une capture reelle du flux du
lidar (facultative, non versionnee) a travers le decodeur et verifie des
proprietes physiquement plausibles (checksum, distances, variete des
angles). S'auto-ignore (`SKIPPED`) si aucune capture n'est presente. Voir
`test/fixtures/README.md` pour en generer une avec le materiel.

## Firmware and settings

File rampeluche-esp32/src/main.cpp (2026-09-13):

#include <Arduino.h>
#include "DriverMotor.h"
#include "pins.hpp"
#include "LidarController.hpp"
#include "RplidarDecoder.hpp"
#include "KeyboardControl.hpp"
#include "WifiTeleopServer.hpp"
#include <WiFi.h>

const uint8_t encoderA = 15;
const uint8_t encoderB = 16;
DriverMotor MotDriver;
LidarController LidCtl;

volatile bool A;
volatile bool B;

//   bool A = digitalRead(encoderA);
//   bool B = digitalRead(encoderB);

volatile long encoderCount = 0;
volatile unsigned long lastInterruptTime = 0;

void IRAM_ATTR encoderISR() {
    A = digitalRead(encoderA);
    B = digitalRead(encoderB);
    if (A && B)
        encoderCount++;
}

WiFiServer server(1234);


void setup() {

    Serial.begin(115200);
    LidCtl.setup();
    WiFi.softAP(
        "ESP32_Control",
        "12345678"
    );

    Serial.println(WiFi.softAPIP());

    server.begin();
    MotDriver.setupDriver();
}


static void applyMotorCommand(Motor &motor, const MotorCommand &cmd)
{
    switch (cmd.action)
    {
        case MotorAction::Forward:
            motor.setMotorForward(cmd.speed);
            break;
        case MotorAction::Backward:
            motor.setMotorBackward(cmd.speed);
            break;
        case MotorAction::Stop:
            motor.stopMotor();
            break;
    }
}

static void applyDriveCommand(const DriveCommand &cmd)
{
    applyMotorCommand(MotDriver.Motors[LEFT], cmd.left);
    applyMotorCommand(MotDriver.Motors[RIGHT], cmd.right);
}

// Affiche les points fraichement decodes par LidCtl.poll() (cf. loop()).
// Remplace l'ancien parseExpressPacket()/CabinData ad-hoc : LidarController
// s'appuie desormais sur lib/RplidarDecoder, qui valide le checksum de
// chaque paquet et se resynchronise seul sur le flux UART si besoin (voir
// test/test_rplidar_decoder pour le detail du format).
void onLidarPoints(const Rplidar::ScanPoint *points, size_t count, void *user_data)
{
    for (size_t i = 0; i < count; i++) {
        Serial.print(points[i].angle_deg);
        Serial.print("\t");
        Serial.println(points[i].distance_mm);
    }
}

void loop() {
    // Serial.println(WiFi.softAPIP());

    WiFiClient client = server.available();
    static bool start = false;
    if (!start)
    {
        delay(2000);
        LidCtl.startExpressScan();
        start = true;
    }
    LidCtl.poll(onLidarPoints);

    WifiTeleopServer teleop(millis());
    while (client.connected())
    {
        // Continuer a vider Serial2 pendant toute la session de pilotage :
        // sinon le petit buffer RX materiel deborde des qu'un client reste
        // connecte (le cas d'usage normal), et le decodage lidar degenere
        // en resynchronisations/erreurs de checksum en continu.
        LidCtl.poll(onLidarPoints);

        if (client.available()) {
            char c = client.read();
            // Serial.println(c);
            applyDriveCommand(teleop.onKeyReceived(c, millis()));
        }
        else {
            WifiTeleopServer::TimeoutResult timeout = teleop.checkTimeout(millis());
            if (timeout.triggered) {
                // securite : plus aucune touche recue, on coupe les moteurs
                applyDriveCommand(timeout.command);
            }
        }
    }
    delay(500);
}

//     pinMode(encoderA, INPUT_PULLUP);
//     pinMode(encoderB, INPUT_PULLUP);

//     attachInterrupt(
//     digitalPinToInterrupt(encoderA),
//     encoderISR,
//     CHANGE
//   );

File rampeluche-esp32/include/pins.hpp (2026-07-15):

#pragma once
#include <Arduino.h>

constexpr uint8_t lidar_mot_ctl_pin = 11;
constexpr uint8_t lidar_rx_pin = 12;
constexpr uint8_t lidar_tx_pin = 13;

#define BIN1 39
#define BIN2 40
#define BPWM 41

#define AIN1 37
#define AIN2 36
#define APWM 35

#define STBY 38

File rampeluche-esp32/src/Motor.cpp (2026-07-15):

#include "Motor.hpp"

Motor::Motor(const uint8_t IN1, const uint8_t IN2, const uint8_t PWM) : m_speed(0), m_IN1(IN1), m_IN2(IN2), m_PWM(PWM)
{
}


void Motor::setupMotor()
{
    pinMode(m_IN1, OUTPUT);
    pinMode(m_IN2, OUTPUT);
    pinMode(m_PWM, OUTPUT);
}
void Motor::stopMotor()
{
    digitalWrite(m_IN1, LOW);
    digitalWrite(m_IN2, LOW);
}

void Motor::setMotorForward(uint8_t per_speed)
{
    per_speed = constrain(per_speed, 0, 100);
    uint8_t speed = per_speed * 200 / 100;
    analogWrite(m_PWM, speed);


    digitalWrite(m_IN1, HIGH);
    digitalWrite(m_IN2, LOW);
}

void Motor::setMotorBackward(uint8_t per_speed)
{
    per_speed = constrain(per_speed, 0, 100);
    uint8_t speed = per_speed * 200 / 100;
    analogWrite(m_PWM, speed);

    digitalWrite(m_IN1, LOW);
    digitalWrite(m_IN2, HIGH);
}

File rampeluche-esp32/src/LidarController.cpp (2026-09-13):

#include "LidarController.hpp"
#include "RplidarProtocol.hpp"

namespace {
constexpr uint8_t kLidarMotorPwmDuty = 100;
// Le moteur du Lidar doit atteindre sa vitesse nominale avant l'envoi de la
// commande Express Scan, faute de quoi le RPLIDAR ignore la requete.
constexpr unsigned long kMotorSpinUpDelayMs = 500;
constexpr size_t kExpressScanPayloadSize = 5;
}

void LidarController::setup()
{
    pinMode(lidar_mot_ctl_pin, OUTPUT);
    Serial2.begin(115200, SERIAL_8N1, lidar_tx_pin, lidar_rx_pin);
}

void LidarController::startExpressScan()
{
    analogWrite(lidar_mot_ctl_pin, kLidarMotorPwmDuty);
    delay(kMotorSpinUpDelayMs);
    while (!Serial2.availableForWrite());

    uint8_t payload[kExpressScanPayloadSize] = {0};
    uint8_t request[Rplidar::requestPacketSize(kExpressScanPayloadSize)];
    size_t len = Rplidar::buildRequestPacket(
        request, static_cast<uint8_t>(RplidarCmd::ExpressScan), payload, sizeof(payload));
    Serial2.write(request, len);
}

void LidarController::poll(Rplidar::StreamDecoder::PointCallback onPoints, void *userData)
{
    int available = Serial2.available();
    if (available <= 0) {
        return;
    }

    uint8_t buf[256];
    size_t toRead = static_cast<size_t>(available) > sizeof(buf) ? sizeof(buf) : static_cast<size_t>(available);
    size_t n = Serial2.readBytes(buf, toRead);
    decoder.feed(buf, n, onPoints, userData);
}

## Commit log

2026-06-13 feat: added cad files
    [ESP32_S3_WROOM_Case.3mf, motormount.3mf, roue_n20.3mf]
2026-06-13 feat: added modeled battery 12V holder
    [battery holder.3mf]
2026-06-13 doc: added current issues
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2026-09-12 fix: rework keyboard motor control and add no-key safety stop
    - Replace the buggy direction/copysign logic in input_key() with a
    clear switch: w/s drive both wheels forward/backward, a/d pivot in
    place, any other key stops the motors via stopMotor(). The previous
    logic relied on std::copysign(1, direction) which was ambiguous when
    direction was 0 (robot idle or just stopped).
    - Name the speed constants (FORWARD_SPEED, BACKWARD_SPEED, TURN_SPEED)
    instead of the speed * multiplier magic numbers.
    - Add a 500ms timeout (KEY_TIMEOUT_MS): if no key is received from the
    TCP client while it stays connected, the motors are stopped
    automatically instead of continuing on the last command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
    [main.cpp]
2026-09-12 feat: add python keyboard client for wifi teleop
    Add tools/keyboard_client.py, a small pynput-based client that
    connects to the ESP32 SoftAP TCP server (192.168.4.1:1234 by default)
    and streams the currently held w/a/s/d key every 150ms (below the
    firmware's 500ms no-key timeout), sending a neutral key on release or
    exit for a responsive stop. q/Esc quits.
    Claude-Session: https://claude.ai/code/session_01CY5CdnmZdCRTYs6atynHzj
2026-09-12 chore: ignore python cache in esp32 project gitignore
    Add __pycache__/ and *.pyc so running tools/keyboard_client.py
    doesn't leave build artifacts as untracked files.
    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
2026-09-12 refactor: extract keyboard control decision logic into testable lib
    Move the key->motor-command decoding and the safety-timeout check out
    of main.cpp into lib/KeyboardControl, as pure functions with no
    Arduino dependency (decodeKey, keyTimedOut). main.cpp now only applies
    the resulting MotorCommand to the actual Motor objects. Behavior is
    unchanged; this only makes the decision logic unit-testable off-target.
2026-09-12 test: add unit tests for keyboard control logic
    Add a native PlatformIO environment (no ESP32/Arduino needed) and a
    Unity test suite covering lib/KeyboardControl:
    - decodeKey for w/a/s/d, an unknown key and the explicit stop signal
    - keyTimedOut, including the exact-boundary case and millis() wraparound
    Run with `pio test -e native`. Documented in test/README a macOS
    PATH gotcha (Homebrew's GNU ar shadowing Apple's ar breaks the native
    link) and its workaround.
    [test_main.cpp]
2026-09-12 feat: add RPLIDAR A2M8 express-scan packet decoder
    Adds lib/RplidarDecoder, a pure (no Arduino dependency, unit-testable via
    `pio test -e native`) decoder for the RPLIDAR A2M8 "Express Scan" capsule
    packets (cmd 0x82 / RPLIDAR_ANS_TYPE_MEASUREMENT_CAPSULED):
    - hasValidSync / hasValidChecksum: header sync nibbles + XOR checksum
    validation, per the SLAMTEC protocol.
    - startAngleDeg / isNewScan: per-packet start angle (Q6) and new-revolution
    flag.
    - decodeCapsulePair: turns two consecutive capsules into 32 (angle, distance)
    points, reproducing the official RPLIDAR SDK algorithm (linear
    interpolation of each point's angle between the two packets' start angles,
    corrected by the cabin's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
    [LidarController.cpp, test_main.cpp]
2026-09-12 test: add real-capture regression test + capture tooling for RPLIDAR A2M8
    - test/test_rplidar_decoder_capture: feeds an optional real UART capture
    (test/fixtures/rplidar_a2m8_express_scan.bin, gitignored, not versioned)
    through Rplidar::StreamDecoder and sanity-checks the result (checksum
    error rate < 5%, distances within the A2M8's physical range, angles
    spread across enough sectors to rule out a stuck/garbage decode).
    Gracefully TEST_IGNOREs when no fixture is present, so `pio test -e
    native` still passes without hardware.
    - tools/capture_rplidar_serial.py: small pyserial script to dump a serial
    port's raw bytes to a file for the duration given, used to produce that
    fixture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
    [capture_rplidar_serial.py, test_main.cpp]
2026-09-13 docs(esp32): add README with code overview and architecture rationale
    Documents the firmware structure (src/include/lib/test/tools), the
    main control flow (Wi-Fi keyboard teleop -> motors, LIDAR parsing),
    the pin mapping, and the key architecture choices: pure/testable
    KeyboardControl logic, the no-key safety stop, the minimal SoftAP+TCP
    protocol, the H-bridge motor API, and the RPLidar express-scan
    decoding. Also lists known tech debt (unused WifiHandler stub, dead
    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
2026-09-13 fix: stop pairing capsules across a lost sync, drain lidar UART during teleop
    Addresses findings from /code-review on PR #3:
    - StreamDecoder::pushByte now clears _hasPrevPacket whenever the byte
    stream loses sync (a byte fails the 0xA/0x5 nibble check). Previously,
    hunting byte-by-byte for resync after a UART gap or noise burst never
    touched _hasPrevPacket, so the next successfully checksummed packet was
    silently paired with a stale, no-longer-adjacent _prevPacket -- producing
    a full batch of plausible-looking but wrong interpolated angles/distances
    with no error signal. Added a regression test
    (test_stream_decoder_does_not_pair_packets_across_a_sync_loss) that fails
    on the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
    [main.cpp, test_main.cpp]
2026-09-13 docs: sync root README and CLAUDE.md with actual esp32 firmware state
    - README.md: replace the vague "Introducing keyboard control / Wifi
    communication" bullets with what's actually implemented (Wi-Fi
    keyboard teleop with safety cutoff, H-bridge differential drive,
    Lidar wired+decoded but unused, Unity test suite), and link to
    rampeluche-esp32/README.md for details.
    - CLAUDE.md: Stack now names the actual transport (SoftAP + raw TCP)
    and motor control scheme (H-bridge, PWM %), and notes Lidar/IMU
    integration status accurately. Architecture gets a one-line summary
    of the main data flow instead of only pointing elsewhere.
    rampeluche-esp32/README.md was checked line-by-line again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
2026-09-13 ci: run native Unity tests and esp32-s3 build on push/PR
    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
2026-09-13 docs: document RplidarDecoder module and LidarController.poll()
    - CLAUDE.md (Stack/Sensors): precise how Lidar frames are decoded now
    (lib/RplidarDecoder: sync/checksum + angle-distance interpolation,
    pure logic unit-tested off-target), still not consumed for navigation.
    - README.md (root): update the Lidar/tests bullets to reflect Express
    Scan decoding and the new RPLidar decoder unit tests.
    - rampeluche-esp32/README.md: rewrite the LIDAR architecture section for
    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
2026-09-13 docs: include subagent name in commit/PR attribution signature
    Update the attribution rule in CLAUDE.md so commit trailers and PR
    footers include the name of the subagent that produced the work
    (e.g. tech-architect, code-generator), inserted alongside the
    session-provided wording without altering it. Main-session work
    keeps the trailer/footer unchanged.
    Claude-Session: https://claude.ai/code/session_019dzZnW5u2w7XBnZ9dRwSXa
2026-09-13 feat: add /feature slash command orchestrating the agent pipeline
    Chains code-generator -> code-reviewer -> documentation-generator for a
    feature/fix request, stopping if the review verdict requires changes.
2026-09-13 docs: update ROADMAP with real state changes (PR#3 conflict, WifiTeleopServer, Motor extraction)
2026-09-13 test: add unit tests for WifiTeleopServer session logic
    Couvre le decodage touche -> DriveCommand et la coupure de securite
    moteur sur timeout (declenchee une seule fois par periode de silence,
    reactivee des qu'une nouvelle touche arrive). Echoue pour l'instant :
    WifiTeleopServer.hpp n'existe pas encore.
2026-09-13 feat: extract Wi-Fi teleop session logic into lib/WifiTeleopServer
    Encapsule l'etat precedemment gere a la main dans la boucle
    while(client.connected()) de main.cpp : decodage touche -> DriveCommand
    (via KeyboardControl::decodeKey) et coupure de securite moteur sur
    timeout client. Logique pure, decouplee d'Arduino.h, testable via
    pio test -e native (voir test/test_wifi_teleop_server).
2026-09-13 refactor: wire main.cpp teleop loop to WifiTeleopServer
    Remplace la gestion inline de lastKeyTime/motorsStopped par
    WifiTeleopServer::onKeyReceived()/checkTimeout(). Comportement
    fonctionnel inchange (meme boucle while(client.connected()), meme
    KEY_TIMEOUT_MS) ; seule la logique de decision est deplacee dans le
    module testable.
2026-09-13 docs: document WifiTeleopServer extraction
    - rampeluche-esp32/README.md: reflect lib/WifiTeleopServer (session logic:
    key decoding + safety-timeout latch, decoupled from Arduino.h) in the
    overview diagram, code structure, architecture rationale and test suites;
    drop the removed input_key() reference; note the still-blocking
    client-read loop as known debt.
    - README.md (root): mention the new unit tests for the teleop session logic.
    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
2026-09-13 chore: add .claudeignore excluding KiCad CAD and other non-code binaries
    Excludes rampeluche-kicad/ (KiCad schematics/PCB, backups, vendored
    symbol libraries), cad/*.3mf, datasheet PDFs/images, the robot photo,
    PlatformIO build artifacts (.pio/), and local IDE/OS clutter — none of
    it useful as text context for Claude Code.
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2026-09-13 feat(lib): extract RplidarProtocol request packet builder
    Logique pure (pas de dependance a Arduino.h), testable sous
    l'environnement native. Remplace les methodes privees
    compute_checksum/build_request de LidarController, dont l'une
    (compute_checksum(size_t)) etait declaree mais jamais implementee ni
    appelee.
2026-09-13 refactor: clean up LidarController structure, drop dead code
    - Utilise Rplidar::buildRequestPacket (lib/RplidarProtocol) au lieu
    des methodes privees dupliquees, une des deux etant morte.
    - Supprime le code commente/obsolete : structs requestPacket/
    responsePacket jamais utilisees, dump hexadecimal de debug sur
    Serial, struct lidarPacket vide et inutilisee, methode
    getSampleRate() declaree mais jamais implementee ni appelee.
    - Renomme les identifiants en camelCase (convention nebula) et
    regroupe la classe en section publique/privee claire.
    - Comportement observable inchange pour l'appelant (main.cpp) :
    memes setup()/startExpressScan()/poll(callback). Le delay(500)
    bloquant de s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
    [LidarController.cpp]
2026-09-13 test: cover RplidarProtocol requestPacketSize helper
    Prepare le fix du buffer request[8] sous-dimensionne dans
    LidarController::startExpressScan() (debordement de pile confirme par
    le code-reviewer sous AddressSanitizer) : couvre le cas avec payload
    Express Scan (5 octets -> 9) et sans payload (-> 4).
    [test_main.cpp]
2026-09-13 fix: size request buffer via requestPacketSize, drop magic number 8
    uint8_t request[8] etait sous-dimensionne : buildRequestPacket() ecrit
    3 (start+cmd+len) + payloadLen (5 pour Express Scan) + 1 (checksum) =
    9 octets, soit un debordement de pile d'un octet a chaque appel de
    startExpressScan(). Rplidar::requestPacketSize(payloadLen) rend ce
    type d'erreur structurellement impossible : le buffer est desormais
    dimensionne a partir de la meme formule que buildRequestPacket().
    [LidarController.cpp]
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
